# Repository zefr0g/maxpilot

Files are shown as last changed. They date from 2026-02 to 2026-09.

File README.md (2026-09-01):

# MaxPilot

     

> Pilotez vos radiateurs électriques en WiFi depuis Home Assistant — carte open-source, ~12 € de composants, 100 % local.

[English version → README.en.md](README.en.md)

| Carte assemblée | Boîtier imprimé en 3D |
|:--:|:--:|
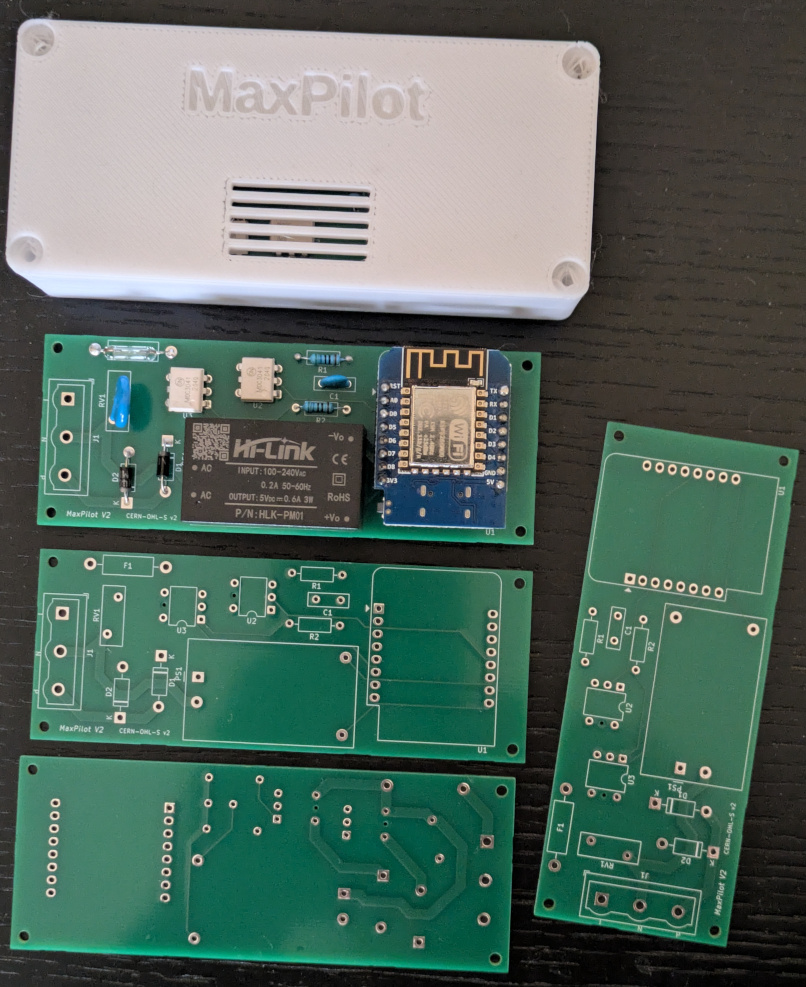
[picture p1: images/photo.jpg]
MaxPilot - carte assemblée
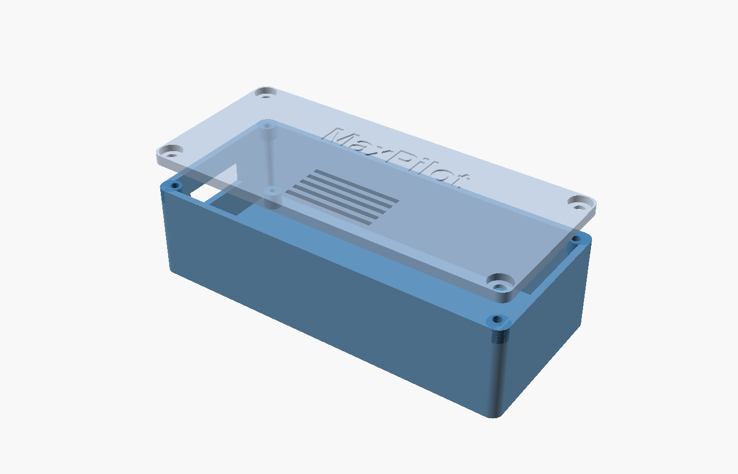
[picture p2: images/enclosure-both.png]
Boîtier MaxPilot
|  |  |

MaxPilot est une carte open-source qui se branche sur le **fil pilote** de vos radiateurs électriques et commande leur mode (Confort, Éco, Hors-gel, Arrêt) depuis Home Assistant, via ESPHome. Plus besoin de programmateur mural : la carte remplace le thermostat central, sans cloud ni abonnement. Elle est conçue autour de composants **peu coûteux et faciles à trouver** (WeMos D1 Mini, optocoupleurs, alimentation HLK-PM01) et se soude entièrement en traversant : accessible à tout amateur d'électronique.

## Pourquoi MaxPilot ?

- **Local et ouvert** — pas de cloud, pas d'application propriétaire : ESPHome + Home Assistant, et vous gardez le contrôle
- **Vraiment pas cher** — ~12 € par radiateur, tout compris (voir [le coût](#coût))
- **Un fil pilote, plusieurs radiateurs** — une carte pilote tous les radiateurs raccordés au même fil pilote
- **Thermostat intégré** — importez n'importe quel capteur de température de Home Assistant et laissez la carte réguler
- **Conçu pour le 230 V** — fusible, varistance, alimentation isolée, distances d'isolement IPC-2221B / IEC 62368-1, boîtier fermé
- **Tout est fourni** — schéma et PCB KiCad, Gerbers, nomenclature, firmware, boîtier OpenSCAD/STL

| | MaxPilot | Module WiFi du commerce (ex. Heatzy Pilote) | Module Z-Wave (ex. Qubino Fil Pilote) |
|---|:--:|:--:|:--:|
| Prix indicatif par radiateur | **~12 €** | ~50 € | ~60 € |
| Fonctionne sans cloud | ✅ | ❌ | ✅ |
| Intégration Home Assistant | native (ESPHome) | via intégration tierce | via Z-Wave JS + clé USB |
| Firmware modifiable | ✅ | ❌ | ❌ |
| Matériel ouvert | ✅ | ❌ | ❌ |
| Montage à faire soi-même | oui (soudure traversante) | non | non |

---

## Sommaire

- [C'est quoi le fil pilote ?](#cest-quoi-le-fil-pilote-)
- [Fonctionnalités](#fonctionnalités)
- [Coût](#coût)
- [Démarrage rapide](#démarrage-rapide)
- [Câblage](#câblage)
- [Schéma](#schéma)
- [Nomenclature](#nomenclature)
- [Firmware ESPHome](#firmware-esphome)
- [Intégration Home Assistant](#intégration-home-assistant)
- [Fabrication du PCB](#fabrication-du-pcb)
- [Boîtier](#boîtier)
- [Sécurité](#sécurité)
- [Contribuer](#contribuer)
- [Licence](#licence)

---

## C'est quoi le fil pilote ?

Le **fil pilote** est le système normalisé en France (protocole GIFAM) pour piloter les radiateurs électriques. En plus de la phase et du neutre, un fil supplémentaire — le fil pilote — transporte un signal de commande dérivé du 230 V. Le radiateur choisit son mode selon la **forme du signal** qu'il reçoit :

| Mode | Ce que fait le radiateur | Signal sur le fil pilote | SSR1 | SSR2 |
|---|---|---|:---:|:---:|
| **Confort** | Chauffe à la température du thermostat | Pas de signal (fil ouvert) | OFF | OFF |
| **Éco** | Réduit la consigne de ~3-4 °C | Sinusoïde complète 230 V | ON | ON |
| **Hors-gel** | Maintient ~7 °C minimum | Alternance négative uniquement | ON | OFF |
| **Arrêt** | Radiateur éteint | Alternance positive uniquement | OFF | ON |

```
Confort (pas de signal)            Éco (sinusoïde complète)

                                        ╭──╮      ╭──╮
                                       ╱    ╲    ╱    ╲
 ──────────────────────        ───────╱──────╲──╱──────╲───
                                    ╲    ╱    ╲    ╱
                                     ╰──╯      ╰──╯

   SSR1: OFF  SSR2: OFF           SSR1: ON   SSR2: ON

Hors-gel (alternance −)            Arrêt (alternance +)

                                        ╭──╮      ╭──╮
                                       ╱    ╲    ╱    ╲
 ───────────────────────────       ────╱──────╲──╱──────╲───
    ╲    ╱    ╲    ╱
     ╰──╯      ╰──╯

   SSR1: ON   SSR2: OFF           SSR1: OFF  SSR2: ON
```

MaxPilot utilise **deux optocoupleurs triac MOC3041M** (SSR1 et SSR2), chacun en série avec une **diode 1N4007** montée en sens opposé. SSR1 laisse passer l'alternance négative, SSR2 l'alternance positive ; les deux ensemble donnent la sinusoïde complète. Les MOC3041M commutent au passage par zéro, donc sans parasites. Le fil pilote ne consomme que quelques milliampères : une seule carte peut piloter **tous les radiateurs raccordés au même fil pilote**.

---

## Fonctionnalités

- ESP8266 (WeMos D1 Mini) avec WiFi intégré, firmware ESPHome
- Sélecteur de mode Confort / Éco / Hors-gel / Arrêt dans Home Assistant
- Thermostat optionnel : capteur de température importé depuis Home Assistant, presets Confort / Éco / Hors-gel / Absent
- Mode restauré après coupure de courant
- Alimentation AC/DC isolée (HLK-PM01, 5 V), fusible 1 A, varistance 275 V
- Optocoupleurs à passage par zéro (MOC3041M)
- PCB 99 × 38 mm, composants traversants uniquement, 4 trous de fixation M2
- Boîtier imprimable en 3D (OpenSCAD + STL) avec aération au-dessus de l'alimentation

---

## Coût

Prix indicatifs 2026 (AliExpress / LCSC / grossistes, hors port), pour une carte :

| Composant | Prix approx. |
|---|--:|
| WeMos D1 Mini | 3,00 € |
| HLK-PM01 | 3,00 € |
| 2 × MOC3041M | 1,20 € |
| Bornier 7,62 mm | 0,70 € |
| Porte-fusible + fusible 1 A | 0,80 € |
| Varistance, diodes, résistances, condensateur | 0,60 € |
| PCB (JLCPCB, lot de 5) | ~2,00 € |
| **Total** | **~11 €** |

---

## Démarrage rapide

1. **Commander le PCB** — envoyez `hardware/gerber/MaxPilot.zip` à JLCPCB, PCBWay, Aisler…
2. **Souder les composants** — voir la [nomenclature](#nomenclature) ; tout est traversant
3. **Flasher le firmware** — branchez le D1 Mini en USB et lancez `esphome run esphome/maxpilot_ch1.yaml` (voir [Firmware ESPHome](#firmware-esphome))
4. **Câbler la carte** — phase, neutre et fil pilote sur le bornier, courant coupé (voir [câblage](#câblage))
5. **Fermer le boîtier** — indispensable, la carte est au 230 V
6. **Ajouter à Home Assistant** — le périphérique est détecté automatiquement par l'intégration ESPHome
7. **Piloter vos radiateurs** — depuis le tableau de bord, des automatisations ou le thermostat

---

## Câblage

> ⚠️ **ATTENTION** : coupez le courant au disjoncteur avant tout câblage et vérifiez l'absence de tension.

La carte se branche sur le bornier 3 points (J1). Le fil pilote de votre radiateur est le fil noir (parfois gris) qui sort du radiateur à côté de la phase et du neutre. Il ne doit **jamais** être raccordé au neutre ni à la terre.

```
                    Bornier J1
                   ┌─────┬─────┬─────┐
                   │  L  │  N  │  P  │
                   └──┬──┴──┬──┴──┬──┘
                      │     │     │
                      │     │     └──── Fil pilote vers le(s) radiateur(s)
                      │     │
                      │     └────────── Neutre (bleu)
                      │
                      └──────────────── Phase (marron ou rouge)

          Depuis le tableau électrique (circuit des radiateurs)
```

Alimentez la carte depuis le **même circuit** que les radiateurs qu'elle pilote : le signal fil pilote est référencé au neutre du radiateur.

---

## Schéma

Le schéma complet est dans `hardware/kicad/MaxPilot.kicad_sch` (KiCad 9).

Schéma

### Architecture

```
Secteur ──► F1 (fusible 1 A) ──► RV1 (varistance) ──► PS1 (HLK-PM01) ──► 5 V
   │                                                          │
   │                                                   U1 (WeMos D1 Mini)
   │                                                    │            │
   │                                                GPIO D3      GPIO D7
   │                                                    │            │
   │                                                R1 (570 Ω)   R2 (570 Ω)
   │                                                    │            │
   ├──────────────────────────────────────────── U2 (MOC3041M)  U3 (MOC3041M)
   │  phase                                            │            │
   │                                               D1 (1N4007)  D2 (1N4007)
   │                                               alternance −  alternance +
   │                                                    └─────┬──────┘
   │                                                          ▼
   └───────────────────────────────────────────────►  P (fil pilote)
```

Les deux optocoupleurs sont branchés en parallèle entre la phase et le fil pilote, chacun à travers sa diode. La partie basse tension (5 V, ESP8266) est isolée du secteur par l'alimentation HLK-PM01 et par les optocoupleurs.

### Brochage

| GPIO | Fonction |
|---|---|
| D3 (GPIO0)  | SSR1 — U2 + D1, alternance négative (Hors-gel, Éco) |
| D7 (GPIO13) | SSR2 — U3 + D2, alternance positive (Arrêt, Éco) |

Les GPIO commandent la LED des optocoupleurs en logique inversée (niveau bas = allumé). D3 étant une broche de démarrage de l'ESP8266, elle reste haute au boot : le radiateur n'est jamais commuté pendant le démarrage.

---

## Nomenclature

| Réf | Qté | Valeur | Description |
|-----|:---:|---|---|
| U1 | 1 | WeMos D1 Mini | Microcontrôleur ESP8266 |
| PS1 | 1 | HLK-PM01 | Alimentation AC/DC 5 V isolée |
| U2, U3 | 2 | MOC3041M | Optocoupleur triac à passage par zéro, DIP-6 — **couper la broche 5 avant soudure** |
| D1, D2 | 2 | 1N4007 | Diodes de sélection d'alternance |
| R1, R2 | 2 | 560–570 Ω | Résistances axiales (limitation LED des optos) |
| C1 | 1 | 22 µF 25 V | Condensateur céramique de découplage 5 V |
| F1 | 1 | 1 A | Fusible lame mini + porte-fusible Keystone 3568 |
| RV1 | 1 | 14D431K | Varistance 275 V AC |
| J1 | 1 | 3 pts, pas 7,62 mm | Bornier à vis, ex. Würth 691311400103, Phoenix MKDS 1,5/3-7,62 |

La nomenclature exportée de KiCad est dans `hardware/MaxPilot.csv`.

---

## Firmware ESPHome

Le firmware est une configuration ESPHome pure, sans code custom.

```
esphome/
├── maxpilot_ch1.yaml                   # une carte = un fichier (nom, broches, secrets)
├── maxpilot_ch1_with_temp.yaml.example # variante avec thermostat
├── secrets.yaml.example
└── common/
    ├── core.yaml             # carte, API, OTA, WiFi de secours, diagnostics
    ├── maxpilot.yaml         # logique fil pilote (SSR + sélecteur de mode)
    └── maxpilot_climate.yaml # thermostat optionnel
```

### 1. Secrets

```bash
cp esphome/secrets.yaml.example esphome/secrets.yaml
# Éditez esphome/secrets.yaml : WiFi et clé de chiffrement API (openssl rand -base64 32)
```

### 2. Flasher

```bash
# Premier flash (D1 Mini branché en USB)
esphome run esphome/maxpilot_ch1.yaml

# Mises à jour suivantes en OTA
esphome run esphome/maxpilot_ch1.yaml --device maxpilot-ch1.local
```

Pour une deuxième carte, copiez `maxpilot_ch1.yaml` et changez `name` et `ch_name`.

### 3. Thermostat (optionnel)

Si un capteur de température de la pièce existe dans Home Assistant (Zigbee, BLE, autre ESPHome…), la carte peut réguler elle-même. Voir `esphome/maxpilot_ch1_with_temp.yaml.example` :

```yaml
substitutions:
  temp_sensor_entity: "sensor.temperature_salon"   # votre capteur dans Home Assistant

packages:
  core: !include common/core.yaml
  maxpilot: !include common/maxpilot.yaml
  climate: !include common/maxpilot_climate.yaml
```

| Preset | Consigne | Fil pilote |
|---|:---:|---|
| **Confort** | 19 °C | Confort quand il fait froid, Éco une fois la consigne atteinte |
| **Éco** | 17 °C | idem, autour de 17 °C |
| **Hors-gel** | 7 °C | idem, autour de 7 °C |
| **Absent** | — | Arrêt |

Le thermostat agit toujours à travers le sélecteur de mode : l'état affiché dans Home Assistant est celui réellement envoyé au radiateur.

### 4. Adoption depuis le tableau de bord ESPHome

La configuration déclare `dashboard_import` : une carte déjà flashée peut être adoptée en un clic depuis le tableau de bord ESPHome (« Adopt »), qui récupère la configuration directement depuis ce dépôt.

---

## Intégration Home Assistant

Une fois flashée, MaxPilot est découverte automatiquement par l'intégration ESPHome. Vous trouverez :

- **Fil Pilote CH1** — sélecteur de mode : Confort, Éco, Hors-gel, Arrêt
- **Radiateur CH1** *(si thermostat activé)* — entité climate avec consigne et presets
- Signal WiFi, uptime et version dans les diagnostics

Exemple d'automatisation :

```yaml
automation:
  - alias: "Radiateurs - Éco la nuit"
    triggers:
      - trigger: time
        at: "22:00:00"
    actions:
      - action: select.select_option
        target:
          entity_id: select.maxpilot_ch1_fil_pilote_ch1
        data:
          option: "Éco"
```

---

## Fabrication du PCB

Fichiers Gerber prêts pour JLCPCB, PCBWay, Aisler… dans `hardware/gerber/` (`MaxPilot.zip` contient tout). PCB 2 couches, 1,6 mm, 99 × 38 mm ; les options par défaut du fabricant conviennent.

| Face avant | Face arrière |
|:--:|:--:|
| PCB Face avant | PCB Face arrière |

---

## Boîtier

Un boîtier imprimable en 3D est fourni dans `hardware/enclosure/` (source OpenSCAD + STL). Imprimez en PLA ou PETG, sans supports, face ouverte vers le haut. Le couvercle comporte des fentes d'aération au-dessus de l'alimentation et une découpe pour les fils côté bornier.

Boîtier

- **Vis PCB** : 4 × M2×6 (auto-taraudantes dans les plots)
- **Vis couvercle** : 4 × M3×13 (auto-taraudantes dans les piliers d'angle)

---

## Sécurité

> ⚠️ **ATTENTION : ce projet manipule la tension secteur (230 V AC). Risque d'électrocution mortelle.**
> Coupez toujours le courant avant toute intervention. La carte doit être installée dans un boîtier fermé, hors de portée. Vous êtes responsable de la conformité de votre installation.

Le PCB v2.0 respecte les distances d'isolement IPC-2221B et IEC 62368-1 :
- Clearance secteur ↔ basse tension : ≥ 3,0 mm
- Ligne de fuite (*creepage*) : ≥ 5,0 mm
- Pistes secteur sur la face arrière uniquement, sans via

---

## Contribuer

Photos de montage, retours sur des modèles de radiateurs, corrections et améliorations sont les bienvenus. Voir [CONTRIBUTING.md](CONTRIBUTING.md). Les questions sont ouvertes dans les [Discussions](https://github.com/zefr0g/maxpilot/discussions).

Si ce projet vous est utile, une ⭐ sur le dépôt aide d'autres personnes à le trouver.

---

## Changelog

### v2.1
- Firmware : adoption depuis le tableau de bord ESPHome, thermostat piloté via le sélecteur, secrets uniquement dans le fichier de la carte
- Boîtier v2.4 : piliers de couvercle dans les angles, insertion du PCB sans inclinaison, fentes d'aération
- Documentation : polarité des alternances corrigée (Hors-gel = négative, Arrêt = positive), coût, comparatif
- CI GitHub Actions : validation ESPHome et DRC KiCad

### v2.0
- Distances d'isolement conformes IPC-2221B / IEC 62368-1
- Bornier J1 remplacé par pas 7,62 mm
- Empreinte MOC3041M corrigée (pin 5 NPTH)
- Routage secteur sur face arrière (B.Cu), sans vias
- Trous de fixation M2 aux 4 coins
- Boîtier imprimable en 3D (hardware/enclosure/)

### v1.0
- Premier design fonctionnel

---

## Licence

CERN Open Hardware Licence Version 2 — Strongly Reciprocal (CERN-OHL-S-2.0)

Voir [LICENSE](LICENSE) pour le texte complet.

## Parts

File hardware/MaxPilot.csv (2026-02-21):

Id | Référence | Boîtier | Quantité | Désignation | Fournisseur et réf
1 | F1 | Fuseholder_Blade_Mini_Keystone_3568 | 1 | 1A
2 | C1 | C_Disc_D8.0mm_W2.5mm_P5.00mm | 1 | 22µF
3 | U2,U3 | MOC3041M_DIP6_W7.62mm_NC5 | 2 | MOC3041M (pin 5 NPTH — couper avant soudure)
4 | R2,R1 | R_Axial_DIN0207_L6.3mm_D2.5mm_P10.16mm_Horizontal | 2 | 570
5 | J1 | TerminalBlock_Generic_1x03_P7.62mm_Horizontal | 1 | Bornier 3 pts 7.62mm (ex: Würth 691311400103)
6 | PS1 | Converter_ACDC_HiLink_HLK-PMxx | 1 | HLK-PM01
7 | U1 | WEMOS_D1_mini_light | 1 | WeMos_D1_mini
8 | D1,D2 | D_DO-41_SOD81_P10.16mm_Horizontal | 2 | 1N4007
9 | RV1 | RV_Disc_D12mm | 1 | MOV 275V (14D431K)

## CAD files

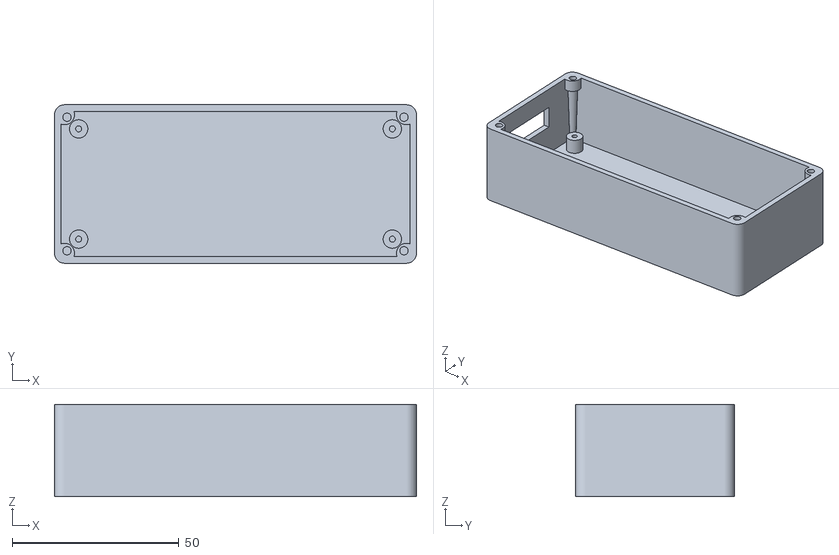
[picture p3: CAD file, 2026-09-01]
hardware/enclosure/MaxPilot_base.stl
108.5 x 47.5 x 27.6

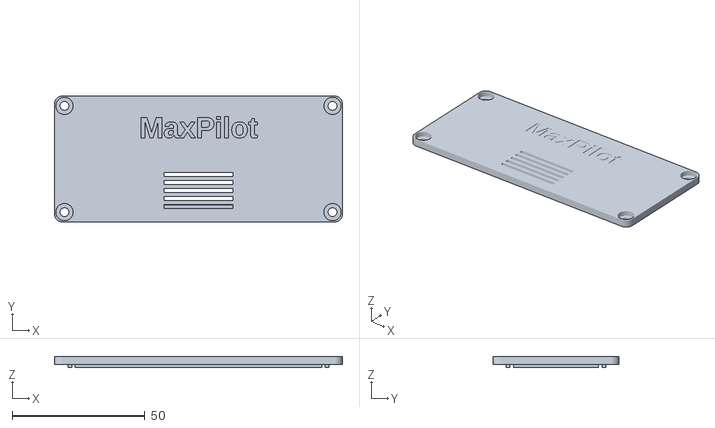
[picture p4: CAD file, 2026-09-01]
hardware/enclosure/MaxPilot_lid.stl
108.5 x 47.5 x 4.00

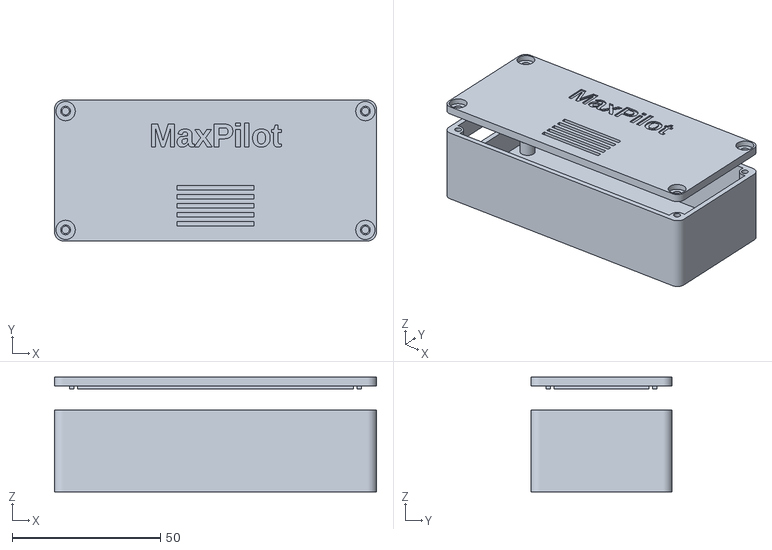
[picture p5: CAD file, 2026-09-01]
hardware/enclosure/MaxPilot_box.stl
108.5 x 47.5 x 38.6

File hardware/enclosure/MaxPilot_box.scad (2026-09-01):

/* ================================================================
   MaxPilot PCB Enclosure — v2.4
   PCB: 99.06 × 38.1 mm, 4× M2 mounting holes
   Mains wire entry: left wall (J1 terminal block)

   Assembly:
     1. Print base (open face up, no supports needed)
     2. Print lid (inner face on build plate, no supports needed)
     3. Drop PCB straight into box — no tilt needed
     4. Secure PCB with 4× M2×6 pan-head screws (self-tapping in PLA)
     5. Place lid (lip locates it), screw down with 4× M3×13 pan-head screws

   Hardware:
     4× M2×6  pan-head screws  (PCB  → M2 bosses at floor)
     4× M3×13 pan-head screws  (lid  → M3 pilots at corner pillars)
   ================================================================ */

$fn = 64;

// ── PCB ──────────────────────────────────────────────────────
pcb_l = 99.06;   // length
pcb_w = 38.1;    // width
pcb_t = 1.6;     // PCB thickness

// Mounting holes relative to PCB corner
mh = [[2.54, 2.54], [96.52, 2.54], [2.54, 35.56], [96.52, 35.56]];

// ── Box ───────────────────────────────────────────────────────
wall     = 2.0;  // wall thickness
floor_t  = 3.0;  // base floor thickness
gap      = 2.7;  // clearance around PCB (was 6.0 — reduced for tighter footprint)
standoff = 5.0;  // boss height = PCB bottom clearance above floor
comp_h   = 16.0; // tallest component above PCB
top_clr  = 2.0;  // clearance above tallest component
corner_r = 3.0;  // exterior corner radius (vertical edges)

// ── Lid ───────────────────────────────────────────────────────
lid_t     = 3.0;  // lid plate thickness
engrave_d = 0.5;  // engraving depth for lid text

// ── Lid alignment lip ─────────────────────────────────────────
// 1 mm ring on the underside of the lid that drops into the box
// interior to locate it precisely before screwing down.
lip_h      = 1.0;   // lip protrusion below lid plate
lip_clr    = 3.0;   // clearance between lip strips and box interior walls
lip_wall_t = 1.5;   // ring wall thickness

// ── M2 PCB bosses (at PCB mounting hole positions) ────────────
boss_d   = 5.5;  // boss outer diameter
boss_h   = standoff;
m2_pilot = 1.8;  // M2 self-tapping pilot hole diameter

// ── Corner lid pillars ────────────────────────────────────────
// Positioned at the 4 interior corners — completely outside the
// PCB footprint so the PCB drops in straight without obstruction.
// Reduced diameter (3.5 mm) matched to the tighter gap.
pillar_rim_d  = 3.5; // diameter at rim (wide end, top)
pillar_foot_d = 2.0; // diameter at foot (narrow end, bottom)

// Lid / M3 screw parameters
m3_pilot  = 2.5;  // M3 self-tapping pilot hole diameter
m3_depth  = 10.0; // pilot depth from pillar tip
lid_clr_d   = 3.3; // M3 clearance hole through lid plate
lid_cbore_d = 6.5; // M3 pan-head counterbore diameter
lid_cbore_h = 2.0; // counterbore depth

// ── J1 terminal block cutout ─────────────────────────────────
j1_cy  = 17.32;
j1_cw  = 22.0;
j1_cz0 = standoff + 5.0;  // wire entry starts just above PCB surface
j1_ch  = pcb_t + 6.0;    // 7.6 mm — enough for 3 × 2.5 mm² leads

// ── HLK-PM01 vent grid ────────────────────────────────────────
// Component centre from KiCad PCB (relative to PCB corner):
//   X = 45.72 − 12.70 = 33.02 mm   Y = 36.905 − 12.70 = 24.205 mm
// Physical footprint: 34 × 20 mm
hlk_pcb_cx = 33.02;    // HLK centre along PCB length axis
hlk_pcb_cy = 24.205;   // HLK centre along PCB width axis
vent_n  = 5;    // number of vent slots
vent_sl = 26.0; // slot length (X direction)
vent_sw = 1.5;  // slot width
vent_sp = 3.0;  // slot pitch (centre-to-centre)

// ── Derived ───────────────────────────────────────────────────
int_l  = pcb_l + 2*gap;
int_w  = pcb_w + 2*gap;
int_h  = standoff + pcb_t + comp_h + top_clr;
pillar_h = int_h;  // full height — pillar runs from floor to rim
ext_l  = int_l + 2*wall;
ext_w  = int_w + 2*wall;
base_h = floor_t + int_h;

px0 = wall + gap;   // PCB X origin in world coords
py0 = wall + gap;   // PCB Y origin in world coords

// HLK-PM01 centre in world / lid coords
hlk_cx = px0 + hlk_pcb_cx;
hlk_cy = py0 + hlk_pcb_cy;

// PCB boss positions (world coords, at PCB mounting holes)
function bp(i) = [px0 + mh[i][0], py0 + mh[i][1]];

// Lid pillar positions (world coords, at interior corners)
// Pillar rim radius = pillar_rim_d/2; centre sits that far from each wall
function lp(i) = [
    (i == 0 || i == 2) ? wall + pillar_rim_d/2 : ext_l - wall - pillar_rim_d/2,
    (i == 0 || i == 1) ? wall + pillar_rim_d/2 : ext_w - wall - pillar_rim_d/2
];

j1_world_cy = py0 + j1_cy;

// ── Helpers ───────────────────────────────────────────────────
module rounded_rect(l, w, h, r) {
    hull()
        for (dx = [r, l-r], dy = [r, w-r])
            translate([dx, dy, 0])
                cylinder(r=r, h=h);
}

// ── Corner lid pillar ─────────────────────────────────────────
// Cone: wide at rim, narrow at foot — no supports needed.
// Top fused into the corner via hull() with the exterior corner arc.
module top_pillar(i) {
    pos = lp(i);
    z0  = base_h - pillar_h;

    // Exterior rounded-corner arc centre for this pillar's corner
    cx = (i == 0 || i == 2) ? corner_r : ext_l - corner_r;
    cy = (i == 0 || i == 1) ? corner_r : ext_w - corner_r;

    fuse_h = 4.0;  // depth of the fused zone from the rim downward

    difference() {
        union() {
            translate([pos[0], pos[1], z0])
                cylinder(d1=pillar_foot_d, d2=pillar_rim_d, h=pillar_h);
            hull() {
                translate([pos[0], pos[1], base_h - fuse_h])
                    cylinder(d=pillar_rim_d, h=fuse_h);
                translate([cx, cy, base_h - fuse_h])
                    cylinder(r=corner_r, h=fuse_h);
            }
        }
        // M3 blind pilot hole from rim downward
        translate([pos[0], pos[1], base_h - m3_depth])
            cylinder(d=m3_pilot, h=m3_depth + 0.01);
    }
}

// ── Base ──────────────────────────────────────────────────────
module base() {
    union() {
        // Hollow shell with J1 wire-entry cutout
        difference() {
            rounded_rect(ext_l, ext_w, base_h, corner_r);
            translate([wall, wall, floor_t])
                cube([int_l, int_w, int_h + 0.01]);
            translate([-0.01, j1_world_cy - j1_cw/2, floor_t + j1_cz0])
                cube([wall + 0.02, j1_cw, j1_ch]);
        }

        // M2 PCB bosses at mounting hole positions
        for (i = [0:3])
            difference() {
                translate([bp(i)[0], bp(i)[1], floor_t])
                    cylinder(d=boss_d, h=boss_h);
                translate([bp(i)[0], bp(i)[1], floor_t + boss_h - 4.0])
                    cylinder(d=m2_pilot, h=4.1);
            }

        // Corner lid pillars
        for (i = [0:3])
            top_pillar(i);
    }
}

// ── Lid ───────────────────────────────────────────────────────
module lid() {
    difference() {
        union() {
            // Main lid plate
            rounded_rect(ext_l, ext_w, lid_t, corner_r);

            // ── Alignment lip ─────────────────────────────────
            // Four separate strips (not a closed ring) that drop 1 mm
            // into the box interior. Stopping before the corner pillar
            // zones avoids any collision with the hull fillet geometry.
            // stop margin past the pillar rim edge on each side
            let(ls = pillar_rim_d/2 + 1.0) {
                // Left strip
                translate([wall + lip_clr,
                           wall + lip_clr + ls, -lip_h])
                    cube([lip_wall_t, int_w - 2*(lip_clr + ls), lip_h]);
                // Right strip
                translate([ext_l - wall - lip_clr - lip_wall_t,
                           wall + lip_clr + ls, -lip_h])
                    cube([lip_wall_t, int_w - 2*(lip_clr + ls), lip_h]);
                // Front strip
                translate([wall + lip_clr + ls,
                           wall + lip_clr, -lip_h])
                    cube([int_l - 2*(lip_clr + ls), lip_wall_t, lip_h]);
                // Back strip
                translate([wall + lip_clr + ls,
                           ext_w - wall - lip_clr - lip_wall_t, -lip_h])
                    cube([int_l - 2*(lip_clr + ls), lip_wall_t, lip_h]);
            }
        }

        // M3 clearance holes + counterbores aligned with corner pillars
        // Extended downward through the lip so the screw passes cleanly
        for (i = [0:3]) {
            translate([lp(i)[0], lp(i)[1], -lip_h - 0.01])
                cylinder(d=lid_clr_d, h=lid_t + lip_h + 0.02);
            translate([lp(i)[0], lp(i)[1], lid_t - lid_cbore_h])
                cylinder(d=lid_cbore_d, h=lid_cbore_h + 0.01);
        }
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

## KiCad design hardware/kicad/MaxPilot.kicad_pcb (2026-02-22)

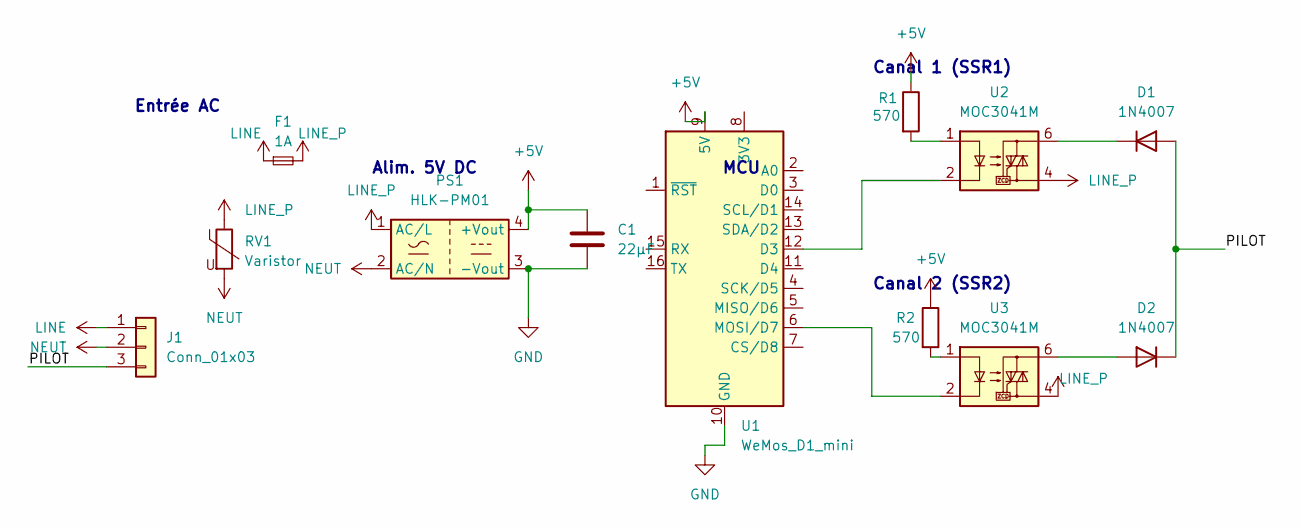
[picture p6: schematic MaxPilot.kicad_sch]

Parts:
C1: 22µF; C_Disc_D8.0mm_W2.5mm_P5.00mm
D1, D2: 1N4007; D_DO-41_SOD81_P10.16mm_Horizontal
F1: 1A; R_Axial_DIN0411_L9.9mm_D3.6mm_P15.24mm_Horizontal
J1: Conn_01x03; TerminalBlock_Generic_1x03_P7.62mm_Horizontal
PS1: HLK-PM01; Converter_ACDC_HiLink_HLK-PMxx
R1, R2: 570; R_Axial_DIN0207_L6.3mm_D2.5mm_P10.16mm_Horizontal
RV1: Varistor; RV_Disc_D12mm_W4.5mm_P7.5mm
U1: WeMos_D1_mini; WEMOS_D1_mini_light
U2, U3: MOC3041M; MOC3041M_DIP6_W7.62mm_NC5

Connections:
+5V: C1.1, PS1.4 (+Vout), R1.1, R2.1, U1.9 (5V)
/PILOT: D1.2 (A), D2.1 (K), J1.3
GND: C1.2, PS1.3 (-Vout), U1.10 (GND)
LINE: F1.1, J1.1
LINE_P: F1.2, PS1.1 (AC/L), RV1.1, U2.4, U3.4
NEUT: J1.2, PS1.2 (AC/N), RV1.2
unnamed: D1.1 (K), U2.6
unnamed: D2.2 (A), U3.6
unnamed: R1.2, U2.1
unnamed: R2.2, U3.1
unnamed: U1.12 (D3), U2.2
unnamed: U1.6 (MOSI/D7), U3.2

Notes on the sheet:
Entrée AC
Alim. 5V DC
Canal 1 (SSR1)
Canal 2 (SSR2)
MCU

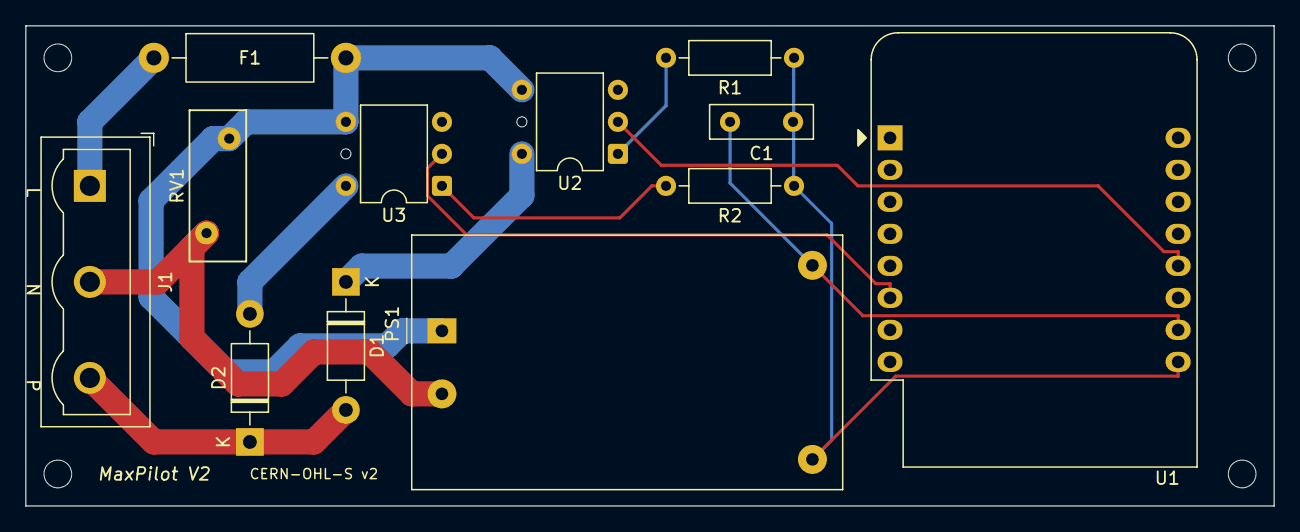
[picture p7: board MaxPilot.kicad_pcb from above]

Board: 2 copper layers, 99.1 x 38.1 mm, 16 parts (0 on the bottom side), 12 nets.

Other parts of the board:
H1, H2, H3, H4: MountingHole_2.2mm_M2

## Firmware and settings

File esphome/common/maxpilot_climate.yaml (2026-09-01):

# Optional thermostat. Imports a room temperature sensor from Home Assistant
# and toggles the pilot wire between Confort (heating) and Éco (idle) around
# the setpoint. Requires the substitution `temp_sensor_entity`.
#
# Thermostat optionnel. Importe un capteur de température depuis Home
# Assistant et bascule le fil pilote entre Confort (chauffe) et Éco (repos)
# autour de la consigne. Nécessite la substitution `temp_sensor_entity`.

sensor:
  - platform: homeassistant
    name: "Température ${ch_name}"
    id: room_temp
    entity_id: ${temp_sensor_entity}
    unit_of_measurement: "°C"
    device_class: temperature
    accuracy_decimals: 1
    filters:
      - filter_out: nan

climate:
  - platform: thermostat
    name: "Radiateur ${ch_name}"
    id: fil_pilote_climate
    icon: "mdi:radiator"
    sensor: room_temp
    visual:
      min_temperature: 7
      max_temperature: 28
      temperature_step: 0.5
    min_idle_time: 5min
    min_heating_off_time: 5min
    min_heating_run_time: 5min
    heat_deadband: 0.5
    heat_overrun: 0.5
    # The select drives the SSRs, so every mode change goes through it and
    # Home Assistant always shows the real pilot wire state.
    heat_action:
      - select.set:
          id: fil_pilote_select
          option: "Confort"
    idle_action:
      - select.set:
          id: fil_pilote_select
          option: "Éco"
    off_mode:
      - select.set:
          id: fil_pilote_select
          option: "Arrêt"
    default_preset: Confort
    preset:
      - name: Confort
        default_target_temperature_low: 19
        mode: heat
      - name: Éco
        default_target_temperature_low: 17
        mode: heat
      - name: Hors-gel
        default_target_temperature_low: 7
        mode: heat
      - name: Absent
        default_target_temperature_low: 7
        mode: "off"

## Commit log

2026-02-20 Initial commit: MaxPilot fil pilote radiator controller
    Open-source KiCad project for a 2-channel "fil pilote" radiator
    controller based on ESP D1 Mini (ESP8266) with ESPHome.
    Includes schematic, PCB layout, Gerber manufacturing files,
    BOM, ESPHome configuration example, and bilingual documentation.
    Licensed under CERN-OHL-S-2.0.
    [MaxPilot-B_Cu.gbr, MaxPilot-B_Mask.gbr, MaxPilot-B_Paste.gbr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]
2026-02-20 Improve README for non-technical users, add board photo
    Add plain-language intro, quick start guide, wiring diagram,
    Home Assistant integration with example automations, and
    practical mode descriptions. Include assembled board photo.
2026-02-20 Add v2 improvements section, specify BOM component values
    Specify C1 as 22µF 25V ceramic and RV1 as MOV 275V (14D431K).
    Add bilingual "Possible Improvements (v2)" section documenting
    fuse sizing, output protection, and creepage distance considerations.
2026-02-20 Add DRC findings to v2 improvements section
    Document specific clearance violations found by DRC: NEUT trace
    0.44mm from D1 pad (IPC requires >2.5mm for 230V), J1 terminal
    block pad spacing insufficient, and unconnected traces on U3/R2.
2026-02-20 Revamp ESPHome config: select entity + optional temp sensor
    Replace raw SSR switches with a single "Fil Pilote" select entity
    (Confort/Éco/Hors-gel/Arrêt). SSRs are now internal. Add optional
    room temperature sensor imported from Home Assistant via substitution.
    Include example config with temperature sensor enabled.
2026-02-20 Add optional thermostat climate control with temperature presets
    When a room temperature sensor is configured, a climate entity can be
    added to automatically switch between Confort/Éco based on room
    temperature. Includes Confort (19°C), Éco (17°C), Hors-gel (7°C)
    and Absent presets.
2026-02-20 Move KiCad and Gerber files to hardware/ directory
    Organize project structure:
    - hardware/kicad/ — KiCad schematic, PCB and project files
    - hardware/gerber/ — manufacturing Gerber and drill files
    - hardware/ — BOM and component placement files
    [MaxPilot-B_Cu.gbr, MaxPilot-B_Mask.gbr, MaxPilot-B_Paste.gbr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]
2026-02-21 Add safety DRC rules for 230V mains (v2 prep)
    Create MaxPilot.kicad_dru with IPC-2221B / IEC 62368-1 compliant
    constraints:
    - Mains-to-LV clearance: 3.0 mm minimum
    - Mains-to-LV creepage: 5.0 mm minimum
    - Mains internal clearance (LINE/NEUT/PILOT): 2.5 mm minimum
    (flags J1 5.08 mm pitch → 7.62 mm pitch required)
    Raise "Line" net class clearance in .kicad_pro from 0.5 mm to 3.0 mm.
    Running DRC will now report all violations to fix in v2 layout.
2026-02-21 Add local footprint library with 3-pin 7.62mm terminal block
    - MaxPilot.pretty/TerminalBlock_Generic_1x03_P7.62mm_Horizontal.kicad_mod
    Derived from Wuerth 691311400102 (2-pin), extended to 3 pins.
    Pad-to-pad edge gap = 7.62 - 2.54 = 5.08mm (passes 2.5mm clearance rule).
    - fp-lib-table: registers MaxPilot.pretty as project-local footprint library
    To use in PCB editor: right-click J1 → Change Footprint →
    select MaxPilot:TerminalBlock_Generic_1x03_P7.62mm_Horizontal
2026-02-21 Fix footprint: remove invalid semicolon comments
    KiCad S-expression parser does not support ; comments.
2026-02-21 Add Net-(D2-Pad2) to Line net class
    This net carries fused mains live voltage (AC/L input to PS1,
    fuse output to optocoupler TRIAC outputs) and must be treated
    as mains, not LV. Fixes 9 false DRC violations where it was
    being compared against NEUT with the Mains_to_LV rules.
2026-02-21 Exclude same-footprint violations from mains DRC rules
    MOC3041M (U2/U3) has NC pin 5 between its two mains pins (4/6)
    and only 7.62mm between LV and mains pin rows — the component
    handles isolation internally. Exclude intra-footprint violations
    with A.Parent != B.Parent condition.
2026-02-21 Add LINE_P and Net-(D2-Pad2) to Line net class
    LINE_P is the fuse-protected mains live net and must be treated
    as mains voltage (2mm traces, 3mm/5mm clearance/creepage rules).
    Also restores Net-(D2-Pad2) which KiCad dropped on file save.
2026-02-21 Update Line net class: add Net-(D1-K) and Net-(D2-A), remove stale Net-(D2-Pad2)
    Net-(D1-K): U2 pin 6 → D1 cathode (mains TRIAC output)
    Net-(D2-A): U3 pin 6 → D2 anode (mains TRIAC output)
    Net-(D2-Pad2) no longer exists in the redesigned schematic.
2026-02-21 Add MOC3041M NC pad 5 to Line net class
    Pin 5 of MOC3041M is the substrate/NC pin on the mains (TRIAC)
    side, physically between pins 4 and 6 which are both mains.
    Wildcard pattern *NC-Pad5* matches unconnected-(U2-NC-Pad5)
    and unconnected-(U3-NC-Pad5), resolving 6 false DRC violations.
2026-02-21 Restore Line clearance to 3.0mm; add MOC3041M NC-Pad5 nets
    - Line net class clearance: 0.5mm → 3.0mm (KiCad had reset it)
    FreeRouting uses net class clearance, so this is critical for
    correct autorouting between mains nets.
    - Add unconnected-(U2-NC-Pad5) and unconnected-(U3-NC-Pad5) to
    Line class: pin 5 is the mains-side substrate of MOC3041M,
    physically between mains pins 4 and 6.
    With 3.0mm Line clearance, re-running FreeRouting should route
    all mains traces with sufficient separation.
2026-02-21 Set Line net class clearance to 2.5mm for FreeRouting
    FreeRouting uses net class clearance for routing, not DRU rules.
    3.0mm between all mains nets was too tight to route.
    2.5mm is the IPC-2221B minimum between mains conductors themselves.
    The DRU Mains_to_LV_Clearance rule (3.0mm) still enforces correct
    separation between mains and LV nets at DRC time — any remaining
    mains-to-LV violations after autorouting need manual correction.
2026-02-21 PCB v2.0: redesign for IPC-2221B/IEC 62368-1 mains safety compliance
    - Replace J1 terminal block with 7.62mm pitch (was 5.08mm)
    - Add IPC-2221B/IEC 62368-1 DRC rules (clearance ≥3.0mm mains↔LV,
    ≥2.5mm mains↔mains, creepage ≥5.0mm) in MaxPilot.kicad_dru
    - Add MOC3041M_DIP6_W7.62mm_NC5 footprint: pin 5 (TRIAC substrate,
    DO NOT CONNECT) replaced with NPTH mechanical hole
    - Assign mains nets to Line netclass (LINE, NEUT, LINE_P,
    Net-(D1-K), Net-(D2-A)); mains traces at 2mm width
    - Re-route PCB to satisfy safety clearances (DRC: 0 errors)
    - Update README: BOM, safety section, v2 changelog
    [MaxPilot.kicad_pcb, MaxPilot.kicad_sch]
2026-02-21 Update PCB render images for v2.0 layout
2026-02-21 Update schematic SVG export for v2.0
2026-02-21 Regenerate Gerber files for v2.0 PCB layout
    [MaxPilot-B_Cu.gbl, MaxPilot-B_Cu.gbr, MaxPilot-B_Mask.gbr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]
2026-02-21 Add CERN-OHL-S v2 license text to PCB back silkscreen
    [MaxPilot.kicad_pcb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]
2026-02-21 Move CERN-OHL-S v2 license to front silkscreen; regenerate Gerbers and images
    [MaxPilot-B_Cu.gbl, MaxPilot-B_Mask.gbs, MaxPilot-B_Paste.gbp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]
2026-02-21 Add M2 mounting holes, reroute PCB, add 3D printable enclosure
    - Add 4× M2 mounting holes at corners (H1-H4, annotated)
    - Reroute PCB after component repositioning; DRC clean (9 warnings, 0 errors)
    - Add hardware/enclosure/MaxPilot_box.scad: OpenSCAD parametric enclosure
    - Base with 4× M2 boss standoffs, friction-fit lid, J1 wire entry cutout
    - Box exterior ~107 × 46 × 36.6 mm, assembly with 4× M2×6 self-tapping screws
    - Regenerate Gerbers and PCB images for updated layout
    - Switch drill output to single unified .drl file
    [MaxPilot-B_Cu.gbl, MaxPilot-B_Mask.gbs, MaxPilot-B_Paste.gbp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]
2026-02-21 Fix PCB SVG exports: remove title block/drawing sheet legend
    Add --exclude-drawing-sheet to kicad-cli export to remove the KiCad
    frame (grid labels A/B/1/2, Date, Rev, Title, Size fields) from SVGs.
2026-02-21 Fix enclosure CSG: bosses now correctly survive interior subtraction
    Boss cylinders were being fully removed by the interior cavity difference
    because they shared the same z-start (floor_t). Fix: separate into
    union(hollow_shell, bosses_with_holes) so bosses are added after the
    interior subtraction. Also add part variable for STL export, export
    MaxPilot_base.stl and MaxPilot_lid.stl.
    Base: 535 facets (was 15). Lid: 16 facets (rectangular, no curves).
    [MaxPilot_base.stl, MaxPilot_box.scad, MaxPilot_lid.stl]
2026-02-21 Add rounded exterior corners to enclosure (corner_r = 3 mm)
    Use hull() of corner cylinders for vertical edge rounding on base and lid.
    Add corner_r parameter and rounded_rect() helper module. Regenerate STLs.
    [MaxPilot_base.stl, MaxPilot_box.scad, MaxPilot_lid.stl]
2026-02-21 Fix lid STL print orientation: outer face at z=0, lip points up
    Lid was exported with lip at negative z, causing it to appear underground
    in FreeCAD/slicers. Apply flip transform when part="lid" so the flat outer
    face sits on the build plate and the friction-fit lip points upward.
    Preview (part="both") keeps the design orientation unchanged.
    [MaxPilot_box.scad, MaxPilot_lid.stl]
2026-02-21 Add M3 corner ear tabs to secure lid to base
    Tight interior (1 mm PCB clearance) leaves no room for internal posts,
    so 4 external ear tabs protrude from the rounded corners. Each ear is a
    5 mm-radius cylinder hulled to the existing corner, offset 3 mm outward
    along the diagonal.
    - Base: ear boss full height, 2.5 mm pilot hole 10 mm deep (M3 self-tapping)
    - Lid: matching ear extension (lid_t thick), 3.3 mm clearance hole,
    6.5 mm × 2 mm counterbore on outer face for M3 pan head
    - Hardware: 4× M3×12 pan-head screws
    [MaxPilot_base.stl, MaxPilot_box.scad, MaxPilot_lid.stl]
2026-02-21 Fix PCB bosses removed by ear-tab interior re-subtraction
    The outer difference() used to keep ear hulls out of the interior was
    also subtracting the PCB standoff bosses. Move bosses to the outer
    union() so they are added after the interior re-subtraction.
    Base: 979 facets (was 459 with missing bosses, 535 with bosses only).
    [MaxPilot_base.stl, MaxPilot_box.scad]
2026-02-21 Engrave 'MaxPilot' text on lid outer face (0.5 mm deep)
    [MaxPilot_box.scad, MaxPilot_lid.stl]
2026-02-21 Reroute PCB: mains traces moved to B.Cu, no vias
    All LINE/NEUT traces now routed on back copper layer, eliminating vias
    and improving mains isolation. Regenerate Gerbers and PCB images.
    [MaxPilot-B_Cu.gbl, MaxPilot-B_Mask.gbs, MaxPilot-B_Paste.gbp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]
2026-02-21 Update DRC report after reroute fix; PCB clean (9 warnings, 0 errors)
    All 9 remaining violations are expected lib_footprint_mismatch warnings
    for custom/offline footprints (MOC3041M_NC5, HLK-PMxx, WEMOS_D1_mini).
    0 unconnected pads, 0 clearance errors.
2026-02-21 Split bilingual README into FR (README.md) and EN (README.en.md)
    Each file is now monolingual with a link to the other at the top.
    Also fixes Gerber drill file list (MaxPilot.drl, unified PTH+NPTH)
    and adds v2.0 changelog entries (B.Cu mains routing, M2 holes, enclosure).
2026-02-21 Add L/N/P silkscreen labels on J1 terminal block
    [MaxPilot-B_Cu.gbl, MaxPilot-B_Mask.gbs, MaxPilot-B_Paste.gbp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]
2026-02-21 Improve schematic readability
    - Fix 2 diagonal wires in PS1 DC output area (now orthogonal: vertical
    down from +5V symbol then horizontal to C1 top pin)
    - Move +5V power symbol to standard orientation (rot=0, directly above
    PS1 +Vout pin)
    - Add bold section labels: Entrée AC, Alim. 5V DC, MCU, Canal 1 (SSR1),
    Canal 2 (SSR2)
    [MaxPilot.kicad_sch]
2026-02-21 Fix BOM CSV: add missing RV1, correct J1 pitch and U2/U3 footprint
    - Add missing RV1 (275V MOV varistor) — was in schematic/PCB but omitted
    - Fix J1 terminal block footprint: 5.08mm → 7.62mm pitch
    - Fix U2/U3 footprint: generic DIP-6 → MOC3041M_DIP6_W7.62mm_NC5 with
    note about pin 5 NPTH (must clip before soldering)
    [MaxPilot.csv]
2026-02-21 Redesign lid attachment: internal conical pillars instead of ear tabs
    Replace external M3 corner ear tabs with 4 internal conical pillars:
    - Each pillar is dual-purpose: M2 boss at base (PCB standoff, same as
    before) + tapered cone (boss_d=5.5 → pillar_top_d=4.5 mm) reaching
    the box rim + M3×10 blind pilot hole at tip for lid screw
    - Lid is now a flat plate (no friction-fit lip) held by 4× M3×13
    pan-head self-tapping screws — simpler, more rigid than press-fit
    - PCB inserted diagonally (~30° tilt about long axis) to clear pillars,
    then lowered onto bosses and secured with 4× M2×6 as before
    - Box exterior unchanged: 107.06 × 46.1 × 36.6 mm
    [MaxPilot_base.stl, MaxPilot_box.scad, MaxPilot_lid.stl]
2026-02-21 Enclosure: thinner walls, fused pillars, smaller wire cutout
    - wall 3→2.5 mm, gap 1→1.5 mm (same exterior footprint, more interior room)
    - Cone orientation corrected: wide at rim, tapering down
    - Top pillars fused into corner walls via hull() at rim level
    - J1 wire cutout reduced 14.6→7.6 mm tall, raised to wire-entry height
    [MaxPilot_base.stl, MaxPilot_box.scad, MaxPilot_lid.stl]
2026-02-21 README: badges, tagline, BOM cleanup, enclosure section
    - Add shields.io badges (license, ESPHome, KiCad 9, Home Assistant)
    - Add one-line tagline as blockquote
    - Remove KiCad footprint column from BOM tables
    - Fix EN architecture diagram labels (were in French)
    - Add dedicated Enclosure section with screw specs
    - Improve Safety section formatting
2026-02-21 Enclosure v2.3: move lid pillars to corners, increase gap for straight PCB insertion
    Lid pillars moved from PCB mounting hole positions (inside PCB outline)
    to interior box corners — PCB now drops straight in, no tilt needed.
    Gap increased 1.5→6 mm so PCB footprint clears the corner pillars.
    Pillar rim 7→5 mm, foot 5→3 mm to fit within the corner zone.
    Box exterior: 116 × 55 × 33.6 mm (was 107 × 46 mm)
    [MaxPilot_base.stl, MaxPilot_box.scad, MaxPilot_lid.stl]
2026-02-22 update enclosure
    [MaxPilot_base.stl, MaxPilot_box.scad, MaxPilot_lid.stl]
2026-02-22 updated schematics page size, adjusting the box
    [MaxPilot.kicad_pcb, MaxPilot.kicad_sch, MaxPilot_base.stl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]
2026-03-09 schematics SVG: remove cartouche/title block
2026-03-09 Revert "schematics SVG: remove cartouche/title block"
    This reverts commit c28e1fbd5c608b7238ce27610c8ffcaadd30c17b.
2026-09-01 Update enclosure model and add generated box STL
    [MaxPilot_base.stl, MaxPilot_box.scad, MaxPilot_box.stl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]
2026-09-01 Fix half-wave polarity docs, restructure ESPHome for dashboard adopt, add CI and project files
    - README (FR/EN): SSR1/D3 passes the negative half-wave (Hors-gel), SSR2/D7
    the positive one (Arrêt), matching the netlist and the GIFAM standard; the
    architecture diagram now shows both optos feeding the single pilot wire.
    Add "Why MaxPilot", comparison, cost table, enclosure render, modern HA
    automation syntax, contributing section.
    - ESPHome: friendly_name/project/dashboard_import; shared packages free of
    custom secrets; climate drives the mode select; HA temperature sensor moved
    into the climate package; OTA password dropped (API encryption instead).
    - GitHub Actions: esphome confi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
    [maxpilot_climate.yaml]
2026-09-01 Re-export schematic and PCB SVGs without title block; run KiCad CI container as root
    - Schematic SVG exported with --exclude-drawing-sheet and cropped to the
    drawing (no cartouche, no page frame)
    - PCB SVGs re-exported with kicad-cli 9.0.8 (no hidden sheet text)
    - actions/checkout could not write inside the kicad/kicad image, which runs
    as a non-root user; use --user root

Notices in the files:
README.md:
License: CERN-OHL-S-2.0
